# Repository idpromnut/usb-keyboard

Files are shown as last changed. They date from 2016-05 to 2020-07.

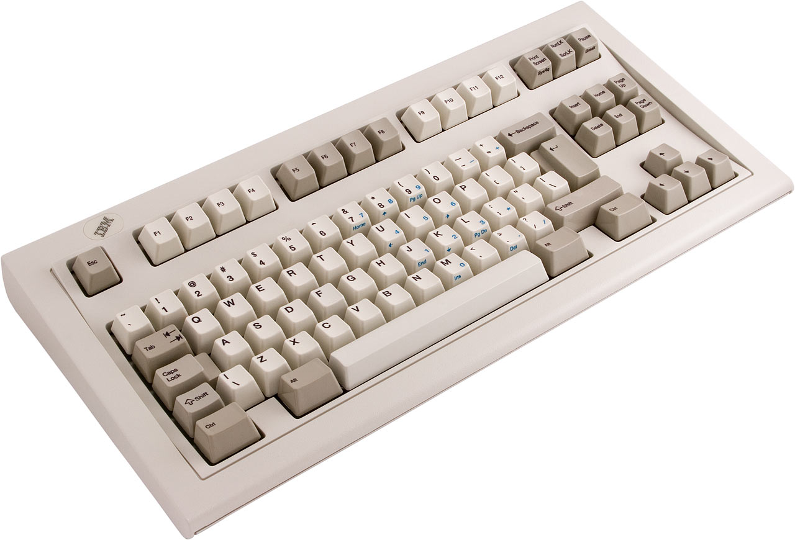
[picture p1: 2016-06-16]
hardware/art/clicky-keyboard.jpg

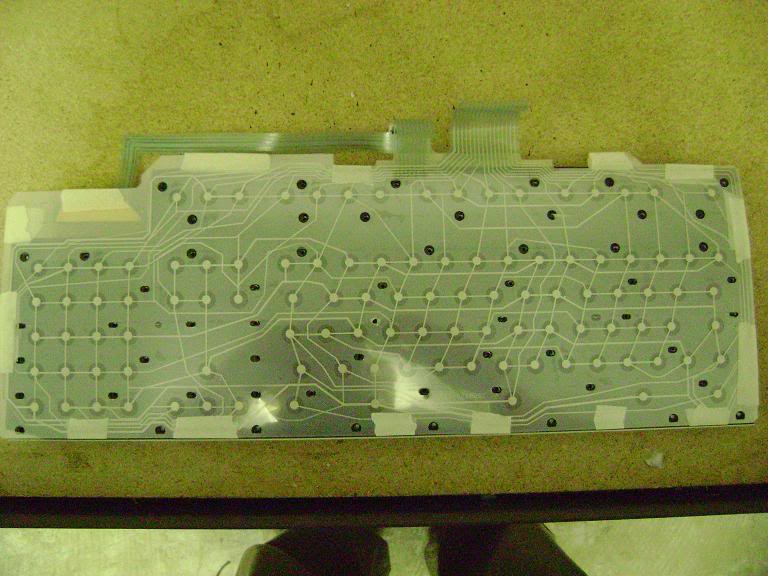
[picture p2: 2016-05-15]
docs/IBM-ModelM-101/CircuitBoard.jpg

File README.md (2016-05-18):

# USB Keyboard Firmware Project
This project started out as a STM32F103 firmware to convert the IBM Model M into a USB keyboard using the existing case, keys and membrane of the IBM Model-M 101 keyboard.

References:

- idollar for an excellent map of keys to the membrane in the Model-M keyboard (https://deskthority.net/workshop-f7/universal-model-m-controller-t9820.html#p207736)

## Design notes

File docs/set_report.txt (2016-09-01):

Name	Value	Bit Offset	Bit Length	Type	
Status	USBD_STATUS_SUCCESS(0)			UsbdStatus	
NtStatus	STATUS_SUCCESS(0)			NTSTATUS	
LengthRequested	1			UInt32	
LengthCompleted	1			UInt32	
Direction	Out(0)			UsbDirection	
Type	Control(0)			UsbTransferType	
EndpointAddress	0x00			Byte	
DeviceInstance	13			Int32	
UrbPtr	18446708891469253408			UInt64	
SetupPacket	USB_SETUP_PACKET{bmRequestType=33,bRequest=9,wValue=512,wIndex=0,wLength=1}			UsbSpec.USB_SETUP_PACKET	
bmRequestType	()			Byte	
bRequest	()			Byte	
wValue	()			UInt16	
wIndex	()			UInt16	
wLength	()			UInt16	
TransferData				BinaryValue

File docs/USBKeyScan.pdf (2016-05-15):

USB | Key | USB | Key | USB | Key | USB | Key
00 | Кнопок нет | 20 | # 3 | 40 | F7 | 61 | 9 PgUp KP
01 | | 21 | $ 4 | 41 | F8 | 62 | 0 Ins KP
02 | | 22 | % 5 | 42 | F9 | 63 | . Del KP
03 | | 23 | ^ 6 | 43 | F10 | 64 | (INT 1)
04 | A | 24 | & 7 | 44 | F11 | 65 | WinMenu
05 | B | 25 | * 8 | 45 | F12 | 68 | F13
06 | C | 26 | ( 9 | 46 | PrtSc | 69 | F14
07 | D | 27 | ) 0 | 47 | Scroll Lock | 6A | F15
08 | E | 28 | Enter | 48 | Pause/Bk | 6B | F16
09 | F | 29 | Esc | 49 | Ins CP | 6C | F17
0A | G | 2A | Back Space | 4A | Home CP | 6D | F18
0B | H | 2B | Tab | 4B | PgUp CP | 6E | F19
0C | I | 2C | Space | 4C | Del CP | 6F | F20
0D | J | 2D | _ - | 4D | End CP | 70 | F21
0E | K | 2E | + = | 4E | PgDn CP | 71 | F22
0F | L | 2F | { [ | 4F | Right CP | 72 | F23
10 | M | 30 | } ] | 50 | Left CP | 73 | F24
11 | N | 31 | | \ | 51 | Down CP | 75 | Help
12 | O | 32 | (INT 2) | 52 | Up CP | 7A | Undo
13 | P | 33 | : ; | 53 | Num Lock | 7B | Cut
14 | Q | 34 | " , | 54 | / KP | 7C | Copy
15 | R | 35 | ~ ` | 55 | * KP | 7D | Paste
16 | S | 36 | < , | 56 | - KP | 7F | Mute
17 | T | 37 | > . | 57 | + KP
18 | U | 38 | ? / | 58 | Enter KP | 80 | VolumeUp
19 | V | 39 | Caps Lock | 59 | 1 End KP | 81 | VolumeDown
1A | W | 3A | F1 | 5A | 2 Down KP | 87 | (INT 3)
1B | X | 3B | F2 | 5B | 3 PgDn KP | 88 | katakana
1C | Y | 3C | F3 | 5C | 4 Left KP | 89 | (INT 4)
1D | Z | 3D | F4 | 5E | 6 Right KP | 8A | kanji
1E | ! 1 | 3E | F5 | 5F | 7 Home KP | 8B | hiragana
1F | @ 2 | 3F | F6 | 60 | 8 Up KP | 8C | furigana
USB | Key | USB | Key | CP | Над стрелками
97 | 5 KP | E0 | Ctrl L | КР | НумПад
9A | Attn / SysRq | E1 | Shif L
9C | Clear | E2 | Alt L
A3 | CrSel | E3 | Win L
A4 | ExSel / SetUp | E4 | Ctrl R
E5 | Shift R
E6 | Alt R
E7 | Win R

По материалам сайта
www.swordgreenline.narod.ru www.mindrunway.msevm.com

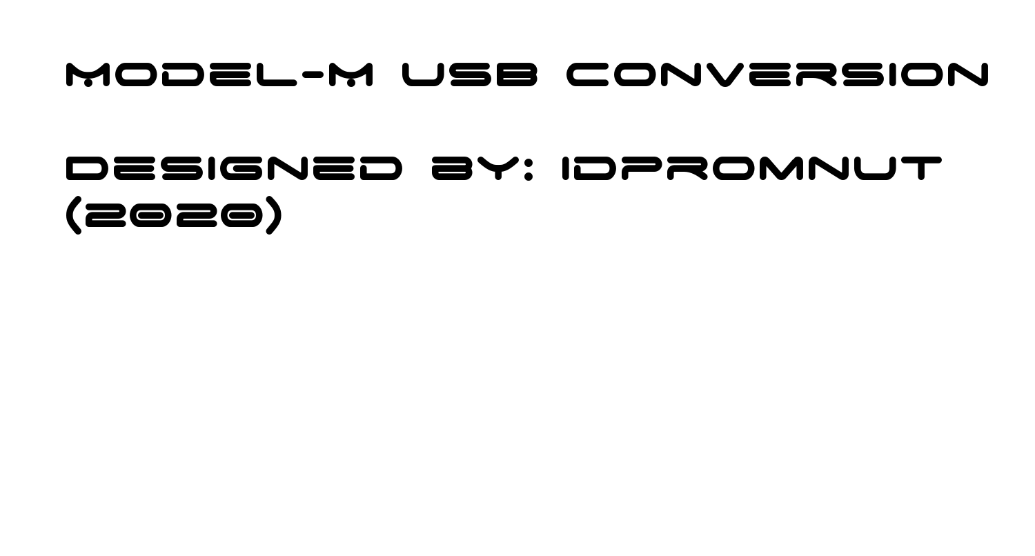
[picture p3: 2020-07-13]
hardware/art/ModelMUsb.png

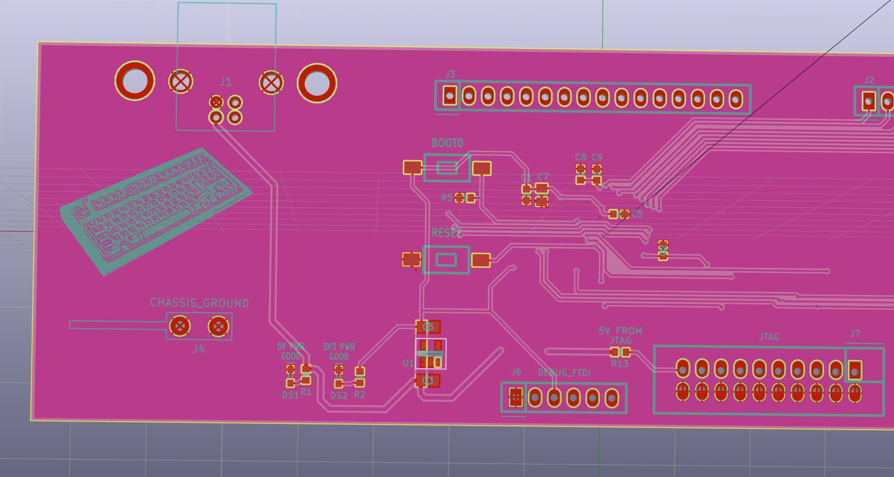
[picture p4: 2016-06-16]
hardware/art/IBM-ModelM-101.png

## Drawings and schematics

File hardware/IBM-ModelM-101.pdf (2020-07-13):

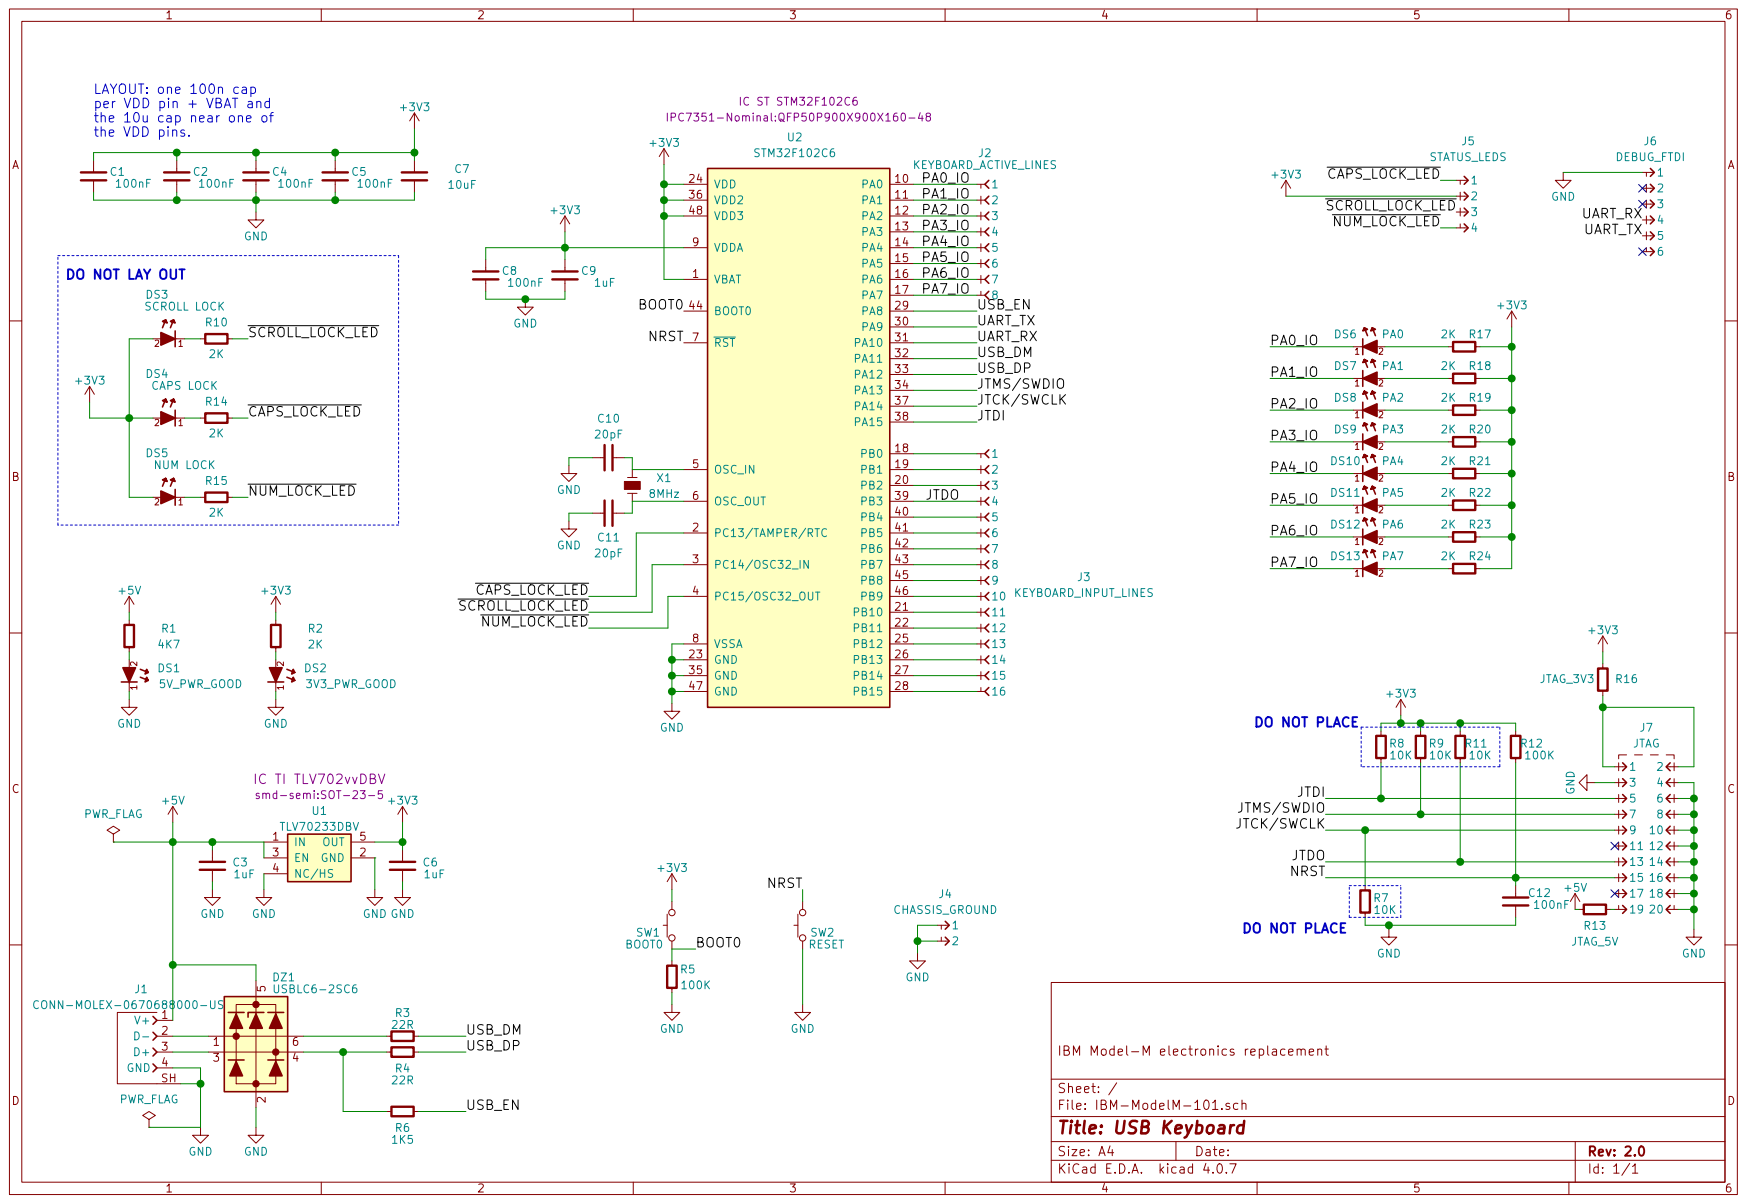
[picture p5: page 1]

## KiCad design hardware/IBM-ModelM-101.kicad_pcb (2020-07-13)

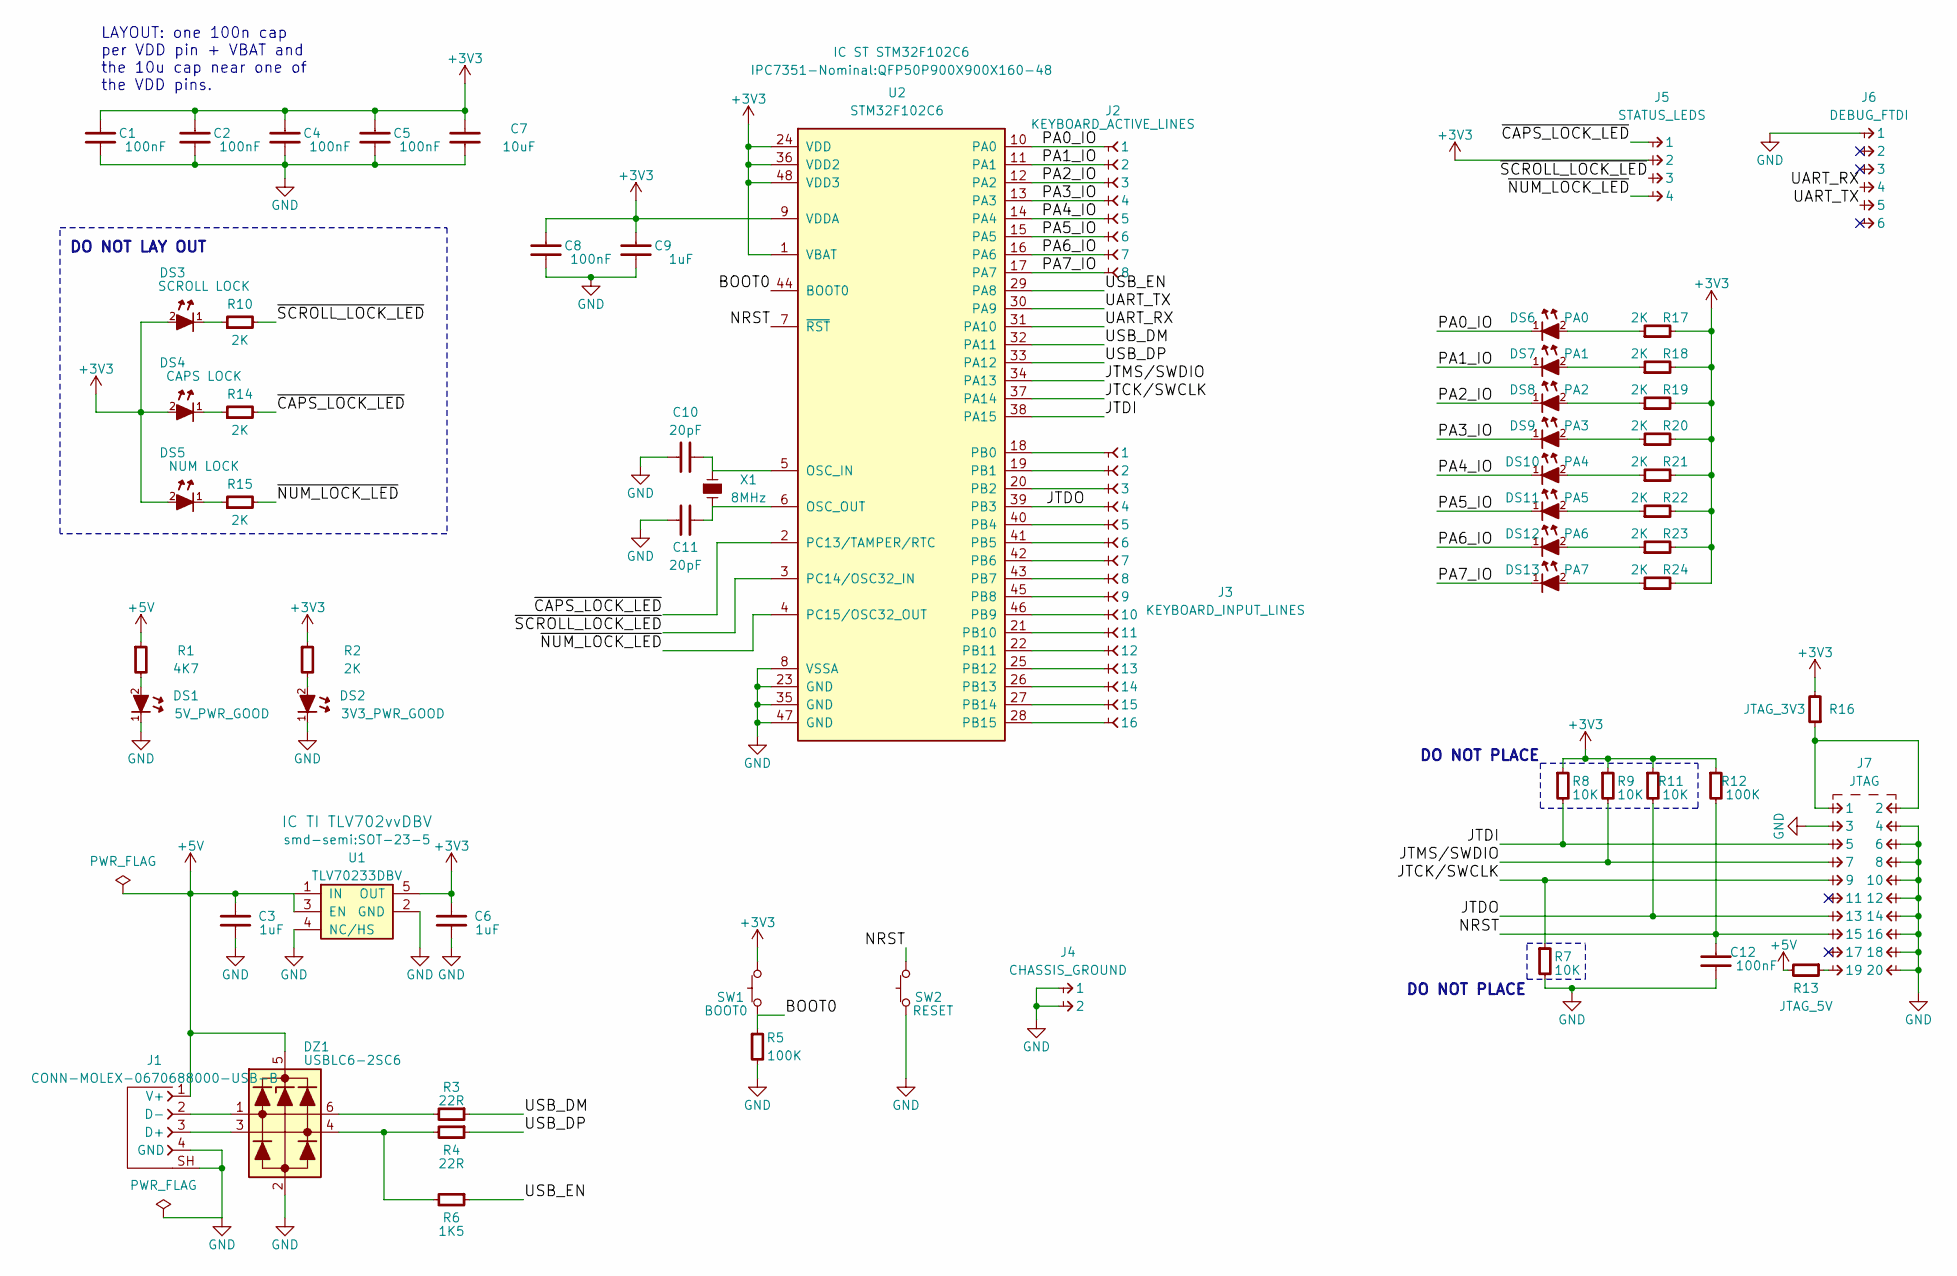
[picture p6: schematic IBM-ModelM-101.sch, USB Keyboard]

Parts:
C1, C2, C4, C5, C8, C12: 100nF; CAPC1608X55
C3, C6: 1uF; CAPC2012X70
C7: 10uF; CAPC2012X70
C9: 1uF; CAPC1608X55
C10, C11: 20pF; CAPC1608X55
DS1: 5V_PWR_GOOD; LED-0603
DS2: 3V3_PWR_GOOD; LED-0603
DS3: SCROLL LOCK; LED-0603
DS4: CAPS LOCK; LED-0603
DS5: NUM LOCK; LED-0603
DS6: PA0; LED-0603
DS7: PA1; LED-0603
DS8: PA2; LED-0603
DS9: PA3; LED-0603
DS10: PA4; LED-0603
DS11: PA5; LED-0603
DS12: PA6; LED-0603
DS13: PA7; LED-0603
DZ1: USBLC6-2SC6; SOT-23-6
J1: CONN-MOLEX-0670688000-USB-B; CONN-MOLEX-0670688000-USB_B
J2: KEYBOARD_ACTIVE_LINES; CONN-100MIL-F-1x8
J3: KEYBOARD_INPUT_LINES; CONN-100MIL-F-1x16
J4: CHASSIS_GROUND; CONN-MOLEX-0197134001-TAB
J5: STATUS_LEDS; CONN-100MIL-M-1x4-SHROUD
J6: DEBUG_FTDI; CONN-100MIL-M-1x6
J7: JTAG; CONN-100MIL-M-2x10-SHROUD
R1: 4K7; RESC1608X50
R2, R10, R14, R15, R17, R18, R19, R20, R21, R22, R23, R24: 2K; RESC1608X50
R3, R4: 22R; RESC1608X50
R5, R12: 100K; RESC1608X50
R6: 1K5; RESC1608X50
R7, R8, R9, R11: 10K; RESC1608X50
R13: JTAG_5V; RESC1608X50
R16: JTAG_3V3; RESC1608X50
SW1: BOOT0; TE-FSMSM
SW2: RESET; TE-FSMSM
U1: TLV70233DBV; SOT-23-5
U2: STM32F102C6; QFP50P900X900X160-48
X1: 8MHz; Abracon-ABM2

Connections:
+3V3: C1.2, C2.2, C4.2, C5.2, C6.1, C7.1, C8.2, C9.2, DS3.2 (A), DS4.2 (A), DS5.2 (A), J5.2, R2.1, R8.1, R9.1, R11.1, R12.1, R16.2, R17.2, R18.2, R19.2, R20.2, R21.2, R22.2, R23.2, R24.2, SW1.2, U1.5 (OUT), U2.1 (VBAT), U2.9 (VDDA), U2.24 (VDD), U2.36 (VDD2), U2.48 (VDD3)
+5V: C3.1, DZ1.5, J1.1 (V+), R1.1, R13.2, U1.1 (IN), U1.3 (EN)
/BOOT0: R5.1, SW1.1, U2.44 (BOOT0)
/JTCK/SWCLK: J7.9, R7.1, U2.37 (PA14)
/JTDI: J7.5, R8.2, U2.38 (PA15)
/JTDO: J3.4, J7.13, R11.2, U2.39 (PB3)
/JTMS/SWDIO: J7.7, R9.2, U2.34 (PA13)
/NRST: C12.2, J7.15, R12.2, SW2.2, U2.7 (~RST)
/PA0_IO: DS6.1 (K), J2.1, U2.10 (PA0)
/PA1_IO: DS7.1 (K), J2.2, U2.11 (PA1)
/PA2_IO: DS8.1 (K), J2.3, U2.12 (PA2)
/PA3_IO: DS9.1 (K), J2.4, U2.13 (PA3)
/PA4_IO: DS10.1 (K), J2.5, U2.14 (PA4)
/PA5_IO: DS11.1 (K), J2.6, U2.15 (PA5)
/PA6_IO: DS12.1 (K), J2.7, U2.16 (PA6)
/PA7_IO: DS13.1 (K), J2.8, U2.17 (PA7)
/UART_RX: J6.4, U2.31 (PA10)
/UART_TX: J6.5, U2.30 (PA9)
/USB_DM: R3.1, U2.32 (PA11)
/USB_DP: R4.1, U2.33 (PA12)
/USB_EN: R6.1, U2.29 (PA8)
/~CAPS_LOCK_LED~: J5.1, R14.2, U2.2 (PC13/TAMPER/RTC)
/~NUM_LOCK_LED~: J5.4, R15.2, U2.4 (PC15/OSC32_OUT)
/~SCROLL_LOCK_LED~: J5.3, R10.2, U2.3 (PC14/OSC32_IN)
GND: C1.1, C2.1, C3.2, C4.1, C5.1, C6.2, C7.2, C8.1, C9.1, C10.2, C11.2, C12.1, DS1.1 (K), DS2.1 (K), DZ1.2, J1.4 (GND), J1.SH (SHIELD), J4.1, J4.2, J6.1, J7.3, J7.4, J7.6, J7.8, J7.10, J7.12, J7.14, J7.16, J7.18, J7.20, R5.2, R7.2, SW2.1, U1.2 (GND), U1.4 (NC/HS), U2.8 (VSSA), U2.23 (GND), U2.35 (GND), U2.47 (GND)
unnamed: C10.1, U2.5 (OSC_IN), X1.1
unnamed: C11.1, U2.6 (OSC_OUT), X1.2
unnamed: DS1.2 (A), R1.2
unnamed: DS2.2 (A), R2.2
unnamed: DS3.1 (K), R10.1
unnamed: DS4.1 (K), R14.1
unnamed: DS5.1 (K), R15.1
unnamed: DS6.2 (A), R17.1
unnamed: DS7.2 (A), R18.1
unnamed: DS8.2 (A), R19.1
unnamed: DS9.2 (A), R20.1
unnamed: DS10.2 (A), R21.1
unnamed: DS11.2 (A), R22.1
unnamed: DS12.2 (A), R23.1
unnamed: DS13.2 (A), R24.1
unnamed: DZ1.1, J1.2 (D-)
unnamed: DZ1.3, J1.3 (D+)
unnamed: DZ1.4, R4.2, R6.2
unnamed: DZ1.6, R3.2
unnamed: J3.1, U2.18 (PB0)
unnamed: J3.2, U2.19 (PB1)
unnamed: J3.3, U2.20 (PB2)
unnamed: J3.5, U2.40 (PB4)
unnamed: J3.6, U2.41 (PB5)
unnamed: J3.7, U2.42 (PB6)
unnamed: J3.8, U2.43 (PB7)
unnamed: J3.9, U2.45 (PB8)
unnamed: J3.10, U2.46 (PB9)
unnamed: J3.11, U2.21 (PB10)
unnamed: J3.12, U2.22 (PB11)
unnamed: J3.13, U2.25 (PB12)
unnamed: J3.14, U2.26 (PB13)
unnamed: J3.15, U2.27 (PB14)
unnamed: J3.16, U2.28 (PB15)
unnamed: J7.1, J7.2, R16.1
unnamed: J7.19, R13.1

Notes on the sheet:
LAYOUT: one 100n cap per VDD pin + VBAT and the 10u cap near one of the VDD pins.
DO NOT PLACE
DO NOT LAY OUT

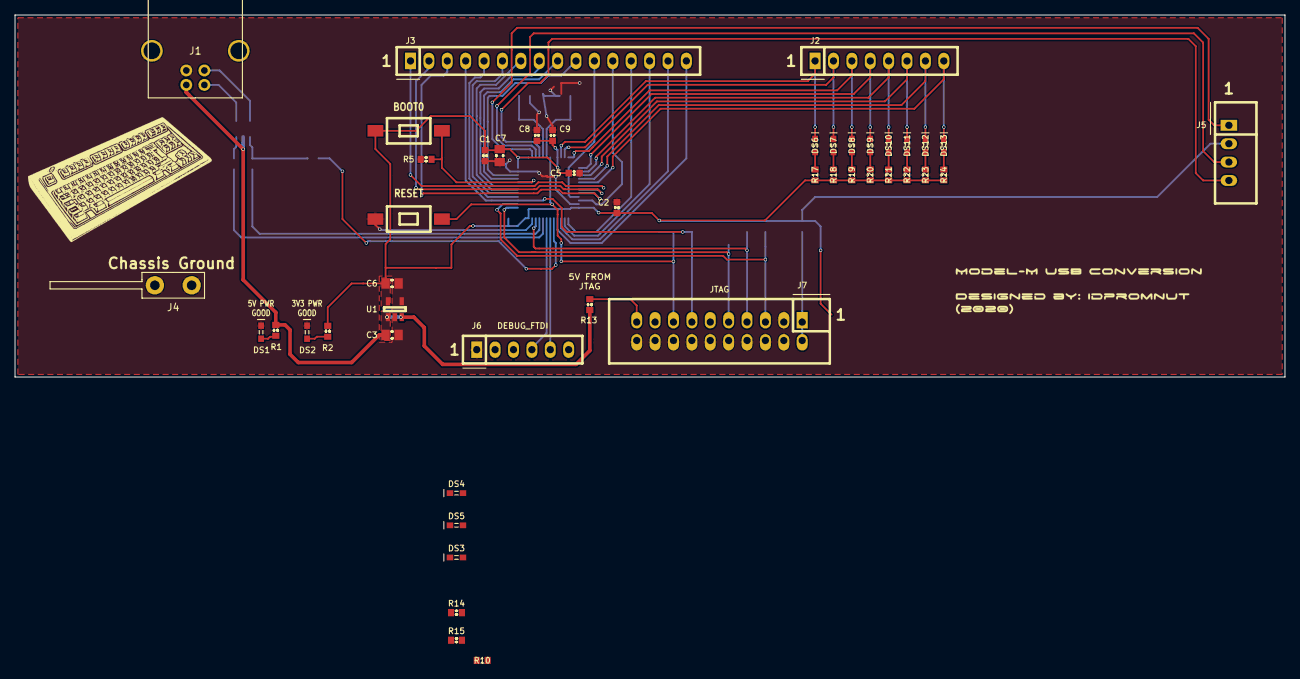
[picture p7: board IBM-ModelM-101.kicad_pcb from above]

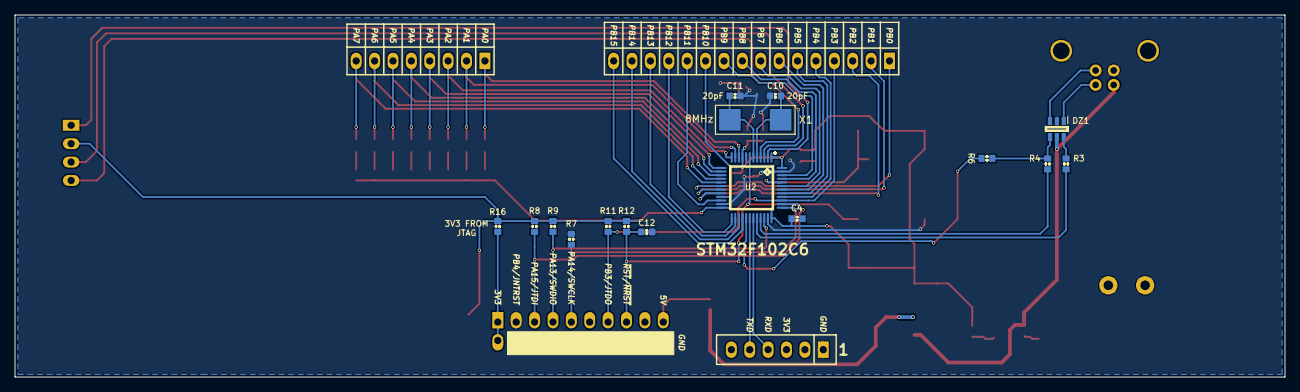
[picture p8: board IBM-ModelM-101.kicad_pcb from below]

Board: 2 copper layers, 175.4 x 50.0 mm, 62 parts (16 on the bottom side), 61 nets.

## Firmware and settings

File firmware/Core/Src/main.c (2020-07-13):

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

/* Includes ------------------------------------------------------------------*/
#include "main.h"
#include "usb_device.h"

/* USER CODE BEGIN Includes */
#include "usb_keyboard.h"
#include "user_interface.h"
#include "usb_ctrl.h"
#include "uart.h"
#include "keyscanner.h"
/* USER CODE END Includes */

UART_HandleTypeDef huart1;

/* USER CODE BEGIN PV */
const uint16_t KEY_DELAY = 100;
const uint16_t REPEAT_DELAY_INITIAL = 500;
const uint16_t REPEAT_DELAY = 30;
static uint8_t refuseInput = 0;
static uint8_t keyRepeating = 0;

/* USER CODE END PV */

void SystemClock_Config(void);
static void MX_GPIO_Init(void);
static void MX_USART1_UART_Init(void);
/* USER CODE BEGIN PFP */
void setRefuseInput();
void clearRefuseInput();
int isRefuseInput();
void setKeyRepeating();
void clearKeyRepeating();
int isKeyRepeating();
void ledUpdateCallback(uint8_t ledState);
/* USER CODE END PFP */

/**
  * @brief  The application entry point.
  * @retval int
  */
int main(void)
{
  /* USER CODE BEGIN 1 */
  uint8_t keysScanned;
  uint8_t scanCodeBufferSize = 8;
  uint8_t scanCodeBuffer[scanCodeBufferSize];
  uint8_t lastScanCode = 0;
  uint8_t modifiers;
  uint8_t lastModifiers = 0;
  uint16_t repeatDelay = KEY_DELAY;
  /* USER CODE END 1 */

  /* MCU Configuration--------------------------------------------------------*/

  /* Reset of all peripherals, Initializes the Flash interface and the Systick. */
  HAL_Init();

  /* Configure the system clock */
  SystemClock_Config();

  /* Initialize all configured peripherals */
  MX_GPIO_Init();
  MX_USART1_UART_Init();
  MX_USB_DEVICE_Init();
  /* USER CODE BEGIN 2 */
  UART_Init(&huart1);
  USB_Control_Init();
  USB_Control_Enable();

  uint8_t VERSION_STRING[] = "USB Keyboard Firmware v2.0\n";

  printf("%s", VERSION_STRING);

  KS_Init();
  UserInterface_Init();

  // toggle LEDs to show board is initialized
  UserInterface_Led_On(NUM_LOCK);
  HAL_Delay(100);
  UserInterface_Led_On(CAPS_LOCK);
  HAL_Delay(100);
  UserInterface_Led_On(SCROLL_LOCK);
  HAL_Delay(800);
  UserInterface_Led_All_Off();
  /* USER CODE END 2 */

  /* Infinite loop */
  /* USER CODE BEGIN WHILE */
  while (1)
  {
    /* USER CODE END WHILE */

    /* USER CODE BEGIN 3 */
	  HAL_Delay(10);
	  modifiers = 0;
	  keysScanned = KS_ReadScanCode(scanCodeBuffer, scanCodeBufferSize, &modifiers);

	  // have the modifiers changed but the scan code stayed the same?
	  if ((modifiers != lastModifiers) && (lastScanCode > 0) && (lastScanCode == scanCodeBuffer[0]))
	  {
		  // stop accepting input until key(s) are released
		  setRefuseInput();
		  lastModifiers = modifiers;
	  }
	  else if(keysScanned > 0 || modifiers != 0)
	  {
		  HAL_Delay(repeatDelay);

		  if ((keysScanned > 0) && (modifiers == lastModifiers))
		  {
			  printf("Key: ");
			  for(uint8_t i = 0; i < keysScanned; i++)
			  {
				  printf("0x%02X ", scanCodeBuffer[i]);
			  }
			  printf(" (modifier 0x%02X)\n", modifiers);

			  if (!isRefuseInput())
			  {
				  USB_Send_Key_Press(scanCodeBuffer[0], modifiers);
				  // if the key is "repeating", reduce the time between repeats
				  if (scanCodeBuffer[0] == lastScanCode)
				  {
					  if (isKeyRepeating())
					  {
						  repeatDelay = REPEAT_DELAY;
					  }
					  else {
						  repeatDelay = REPEAT_DELAY_INITIAL;
						  setKeyRepeating();
					  }
				  }
				  else
				  {
					  repeatDelay = KEY_DELAY;
					  clearKeyRepeating();
				  }
				  lastScanCode = scanCodeBuffer[0];
			  }
			  else if (scanCodeBuffer[0] != lastScanCode)
			  {
				  clearRefuseInput();
				  clearKeyRepeating();
			  }
		  }
		  else
		  {
			  USB_Send_Key_Press(0x00, modifiers);
		  }

		  if (!isRefuseInput())
		  {
			  HAL_Delay(10);
			  USB_Send_All_Keys_Released(0x00);
		  }

		  lastModifiers = modifiers;
	  }
	  else
	  {
		  clearRefuseInput();
		  clearKeyRepeating();
		  repeatDelay = KEY_DELAY;
		  lastScanCode = 0;
		  lastModifiers = 0;
	  }
  }
  /* USER CODE END 3 */
}

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
/* USER CODE BEGIN 4 */
void setRefuseInput() {
	refuseInput = 1;
}

void clearRefuseInput() {
	refuseInput = 0;
}

int isRefuseInput() {
	return refuseInput == 1;
}

void setKeyRepeating() {
	keyRepeating = 1;
}

void clearKeyRepeating() {
	keyRepeating = 0;
}

int isKeyRepeating() {
	return keyRepeating == 1;
}
/* USER CODE END 4 */
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


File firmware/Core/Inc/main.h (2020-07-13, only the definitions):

#define CAPS_LOCK_LED_Pin GPIO_PIN_13
#define CAPS_LOCK_LED_GPIO_Port GPIOC
#define SCROLL_LOCK_LED_Pin GPIO_PIN_14
#define SCROLL_LOCK_LED_GPIO_Port GPIOC
#define NUM_LOCK_LED_Pin GPIO_PIN_15
#define NUM_LOCK_LED_GPIO_Port GPIOC
#define PA0_IO_Pin GPIO_PIN_0
#define PA0_IO_GPIO_Port GPIOA
#define PA1_IO_Pin GPIO_PIN_1
#define PA1_IO_GPIO_Port GPIOA
#define PA2_IO_Pin GPIO_PIN_2
#define PA2_IO_GPIO_Port GPIOA
#define PA3_IO_Pin GPIO_PIN_3
#define PA3_IO_GPIO_Port GPIOA
#define PA4_IO_Pin GPIO_PIN_4
#define PA4_IO_GPIO_Port GPIOA
#define PA5_IO_Pin GPIO_PIN_5
#define PA5_IO_GPIO_Port GPIOA
#define PA6_IO_Pin GPIO_PIN_6
#define PA6_IO_GPIO_Port GPIOA
#define PA7_IO_Pin GPIO_PIN_7
#define PA7_IO_GPIO_Port GPIOA
#define PB0_INPUT_Pin GPIO_PIN_0
#define PB0_INPUT_GPIO_Port GPIOB
#define PB1_INPUT_Pin GPIO_PIN_1
#define PB1_INPUT_GPIO_Port GPIOB
#define PB2_INPUT_Pin GPIO_PIN_2
#define PB2_INPUT_GPIO_Port GPIOB
#define PB10_INPUT_Pin GPIO_PIN_10
#define PB10_INPUT_GPIO_Port GPIOB
#define PB11_INPUT_Pin GPIO_PIN_11
#define PB11_INPUT_GPIO_Port GPIOB
#define PB12_INPUT_Pin GPIO_PIN_12
#define PB12_INPUT_GPIO_Port GPIOB
#define PB13_INPUT_Pin GPIO_PIN_13
#define PB13_INPUT_GPIO_Port GPIOB
#define PB14_INPUT_Pin GPIO_PIN_14
#define PB14_INPUT_GPIO_Port GPIOB
#define PB15_INPUT_Pin GPIO_PIN_15
#define PB15_INPUT_GPIO_Port GPIOB
#define USB_EN_Pin GPIO_PIN_8
#define USB_EN_GPIO_Port GPIOA
#define PB3_INPUT_Pin GPIO_PIN_3
#define PB3_INPUT_GPIO_Port GPIOB
#define PB4_INPUT_Pin GPIO_PIN_4
#define PB4_INPUT_GPIO_Port GPIOB
#define PB5_INPUT_Pin GPIO_PIN_5
#define PB5_INPUT_GPIO_Port GPIOB
#define PB6_INPUT_Pin GPIO_PIN_6
#define PB6_INPUT_GPIO_Port GPIOB
#define PB7_INPUT_Pin GPIO_PIN_7
#define PB7_INPUT_GPIO_Port GPIOB
#define PB8_INPUT_Pin GPIO_PIN_8
#define PB8_INPUT_GPIO_Port GPIOB
#define PB9_INPUT_Pin GPIO_PIN_9
#define PB9_INPUT_GPIO_Port GPIOB

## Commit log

2016-05-13 Check in of basic CDC-based STM32F103 project
2016-05-13 Renamed project to Model-M
    Also enabled CDC USB init in main, that was commented out for testing
    the SemiHosting debug printf().
2016-05-18 Added beginning of schematic for USB replacement PCB
    Schematic and PCB files + documentation for uC.
    [IBM-ModelM-101.kicad_pcb, IBM-ModelM-101.sch]
2016-05-19 Completed most of the keyboard circuit
    Missing the LED connector, decoupling caps, a power LED of some sort,
    and the ground spade connector.
2016-05-19 Finished power and boot/reset circuits
    [IBM-ModelM-101.sch]
2016-05-23 Finished schematic, started work on PCB layout
    [IBM-ModelM-101.sch]
2016-05-24 Working on PCB layout
    Placement is done. Most of the power, decoupling and support routing
    finished.
    [IBM-ModelM-101.kicad_pcb, IBM-ModelM-101.sch]
2016-05-25 Laying out PCB
    [IBM-ModelM-101.kicad_pcb]
2016-05-25 Re-working crystal selection and routing.
    [IBM-ModelM-101.kicad_pcb, IBM-ModelM-101.original.kicad_pcb, IBM-ModelM-101.sch]
2016-06-06 Finished PCB layout
    [IBM-ModelM-101.kicad_pcb, IBM-ModelM-101.sch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]
2016-06-07 Updates + replaced tab header with correct footprint
    [IBM-ModelM-101-B.Cu.gbr, IBM-ModelM-101-B.Mask.gbr, IBM-ModelM-101-B.SilkS.gbr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]
2016-06-09 Fixed unconnected pads + ground plane.
    [IBM-ModelM-101-B.Cu.gbr, IBM-ModelM-101-B.Mask.gbr, IBM-ModelM-101-B.SilkS.gbr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]
2016-06-10 Added artwork and logo
    [IBM-ModelM-101.kicad_pcb]
2016-06-16 Added keyboard art
    Source files used to generate silk screen art for the Model-M PCB.
2016-06-19 Final fixes to schematic and PCB layout
    Fixed silk screen errors, added pin-out information to I/O headers and
    JTAG.
    [IBM-ModelM-101-B.Cu.gbr, IBM-ModelM-101-B.Mask.gbr, IBM-ModelM-101-B.SilkS.gbr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]
2016-06-19 Adjusted output gerber naming
    [IBM-ModelM-101.kicad_pcb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]
2016-07-23 Converting to STM32F102
    [IBM-ModelM-101.kicad_pcb, IBM-ModelM-101.sch]
2016-07-26 Updates to support the STM32F102
    Added STM32F102x6 startup file.
2016-08-14 Most keys, locks working
    All alpha-numerics working along with Scroll, Num andCaps lock keys.
    Shift, Alt and Ctrl not working. Enter key seems to have a bug with it
    as well.
    [IBM-ModelM-101.sch]
2016-09-01 Set report response not working
    Set Report received, but no response is sent.
    [keyscanner.c, main.c]
2016-09-13 Set Report working
    Still need to hook up the set report messages to the LED control code.
2016-09-15 Leds are now working
2017-07-08 Fixed key repeat code
    Keys will now stop repeating if a modifier key is released or pressed.
    Key repeat will pause 500msec before turning on.
    [IBM-ModelM-101.kicad_pcb, IBM-ModelM-101.sch]
2018-04-21 Moved debug UART configuration to main.h
2018-04-21 Refactored directory structure
    Put BSP-related code into src, Drivers and Middleware. BSP-related code is now in src/bsp.
2020-07-13 Updated schematic and PCB layout to fix errors in first revision.
    [IBM-ModelM-101.kicad_pcb, IBM-ModelM-101.sch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]
2020-07-13 Updated usb-keyboard firmware to use STM's STM32CubeIDE.
2020-07-13 Updated copyright information.
    [IBM-ModelM-101.kicad_pcb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]

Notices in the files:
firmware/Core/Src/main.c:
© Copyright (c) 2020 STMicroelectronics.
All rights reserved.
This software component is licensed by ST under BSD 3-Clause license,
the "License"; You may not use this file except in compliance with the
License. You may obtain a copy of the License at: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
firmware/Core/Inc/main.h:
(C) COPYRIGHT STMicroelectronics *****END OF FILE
